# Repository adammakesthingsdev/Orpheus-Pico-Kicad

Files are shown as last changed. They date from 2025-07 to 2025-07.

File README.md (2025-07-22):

# Orpheus Pico
## About this repo
Welcome to the Kicad port of the Orpheus Pico, Hack Club's very own Raspberry Pi Pico compatible microcontroller!
This repository contains both the project files and built gerbers for ordering through JLCPCB.
Please note, **ordering is at your own risk**: I will not be held accountable if you have problems due to mistakes made ordering or issues with the project.

## Ordering
For information on ordering these boards, please refer to ORDERING.md.

## Licensing / other info
An official license for this project is TBD.
For now, you can:
- Use this project for inspiration and derivatives
- Order Orpheus Picos for **non-commercial** purposes: This means you cannot sell them, even at cost

Please get in touch with me (@adammakesthings on Hack Club Slack or adam@hackclub.com) if you are planning on selling Orpheus Picos or ordering large quantities.  

My final ask is that if you order any Orpheus Picos for any reason, I ask that you please keep my name and attribution on them. Again, please get in touch if this doesn't work for you.  
  
-Adam G

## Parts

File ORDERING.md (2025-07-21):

# Ordering info
These options are what I have used to order with JLCPCB. Feel free to tweak if you want, but this is what I recommend!
If an option isn't specified, assume it's the default.

- 2 layers
- Delivery format: Panel by JLCPCB.
  - Optional - this is just a whole lot cheaper!
  - Choose whatever panel size you want - I've had good luck with 2x5 boards and 5mm edges.
- 1.6mm thickness
- Black board color, or something else if you're feeling it!
- If you care about the art and aesthetics, go with ENIG. If you want em as cheap as possible, go with either of the HASLs.
- Mark on PCB: Remove mark. This removes the JLCPCB auto order number that's otherwise arbitrarily placed on your silkscreen
- PCB assembly: Top layer.
  - Unless you're changing something here, just click through the prompts.

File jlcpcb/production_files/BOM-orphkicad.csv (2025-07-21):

Comment | Designator | Footprint | LCSC | Quantity
1K | R10,R2,R7 | R_0402_1005Metric | C11702 | 3
100nF | C1,C13,C14,C2,C3,C4,C5,C6,C8 | C_0402_1005Metric | C1525 | 9
10uF | C15,C16 | C_0402_1005Metric | C15525 | 2
22pF | C10,C9 | C_0402_1005Metric | C1555 | 2
10uF | C12 | C_0805_2012Metric | C15850 | 1
1N5819WS | D1 | D_SOD-323 | C191023 | 1
RP2040 | U1 | QFN-56-1EP_7x7mm_P0.4mm_EP3.2x3.2mm | C2040 | 1
LED_PWR | D2 | LED_0603_1608Metric | C2286 | 1
27R | R3,R4 | R_0402_1005Metric | C25100 | 2
330R | R9 | R_0402_1005Metric | C25104 | 1
470R | R8 | R_0402_1005Metric | C25117 | 1
10K | R1 | R_0402_1005Metric | C25744 | 1
5K1 | R5,R6 | R_0402_1005Metric | C25905 | 2
USB_C_Receptacle_USB2.0_16P | J1 | USB-C-SMD_TYPE-C-6PIN-2MD-073 | C2765186 | 1
W25Q16JVUXIQ | U2 | Winbond_USON-8-1EP_3x2mm_P0.5mm_EP0.2x1.6mm | C2843335 | 1
BTN_BOOT | SW1,SW2,SW3 | SW-SMD_L3.9-W3.0-P4.45 | C455280 | 3
USBLC6-2SC6 | U3 | SOT-23-6 | C5180249 | 1
1uF | C11,C7 | C_0402_1005Metric | C52923 | 2
LED_RGB | D4 | LED-SMD_4P-L1.6-W1.5_XL-1615RGBC-WS2812B | C5349954 | 1
ME2135A33M6G | U4 | SOT-23-6 | C610271 | 1
X322512MSB4SI | X1 | Crystal_SMD_3225-4Pin_3.2x2.5mm | C9002 | 1
LED_USR | D3 | LED_0603_1608Metric | C965804 | 1

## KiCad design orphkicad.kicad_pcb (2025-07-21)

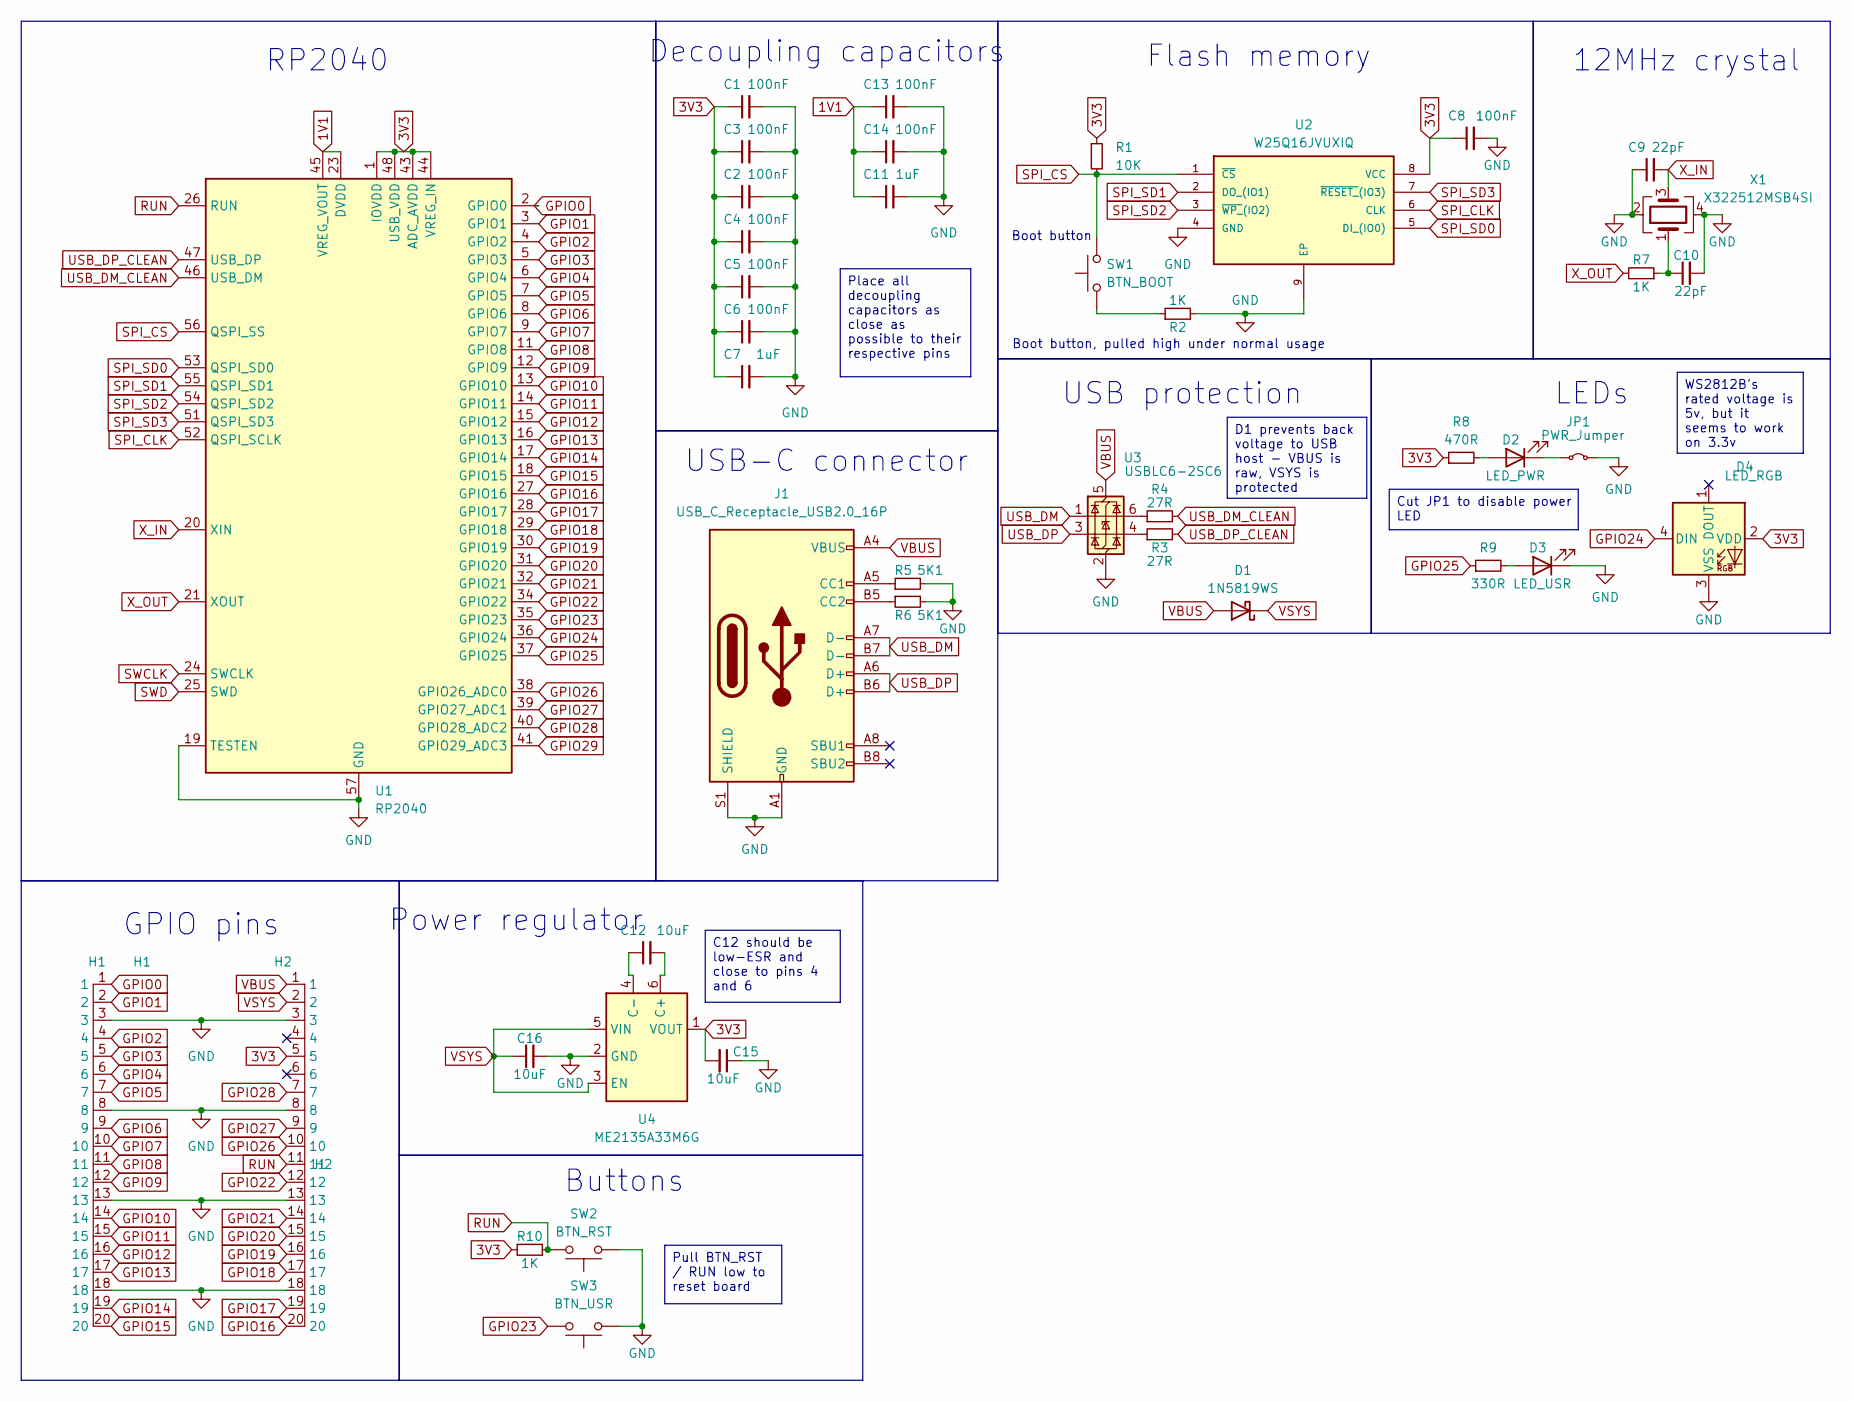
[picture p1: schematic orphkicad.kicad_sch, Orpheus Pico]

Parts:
C1, C2, C3, C4, C5, C6, C8, C13, C14: 100nF; C_0402_1005Metric
C7, C11: 1uF; C_0402_1005Metric
C9, C10: 22pF; C_0402_1005Metric
C12: 10uF; C_0805_2012Metric
C15, C16: 10uF; C_0402_1005Metric
D1: 1N5819WS; D_SOD-323
D2: LED_PWR; LED_0603_1608Metric
D3: LED_USR; LED_0603_1608Metric
D4: LED_RGB; LED-SMD_4P-L1.6-W1.5_XL-1615RGBC-WS2812B
H1: H1; OrphPicoHeaders
H2: H2; OrphPicoHeaders
J1: USB_C_Receptacle_USB2.0_16P; USB-C-SMD_TYPE-C-6PIN-2MD-073
JP1: PWR_Jumper; SolderJumper-2_P1.3mm_Bridged2Bar_RoundedPad1.0x1.5mm
R1: 10K; R_0402_1005Metric
R2, R7, R10: 1K; R_0402_1005Metric
R3, R4: 27R; R_0402_1005Metric
R5, R6: 5K1; R_0402_1005Metric
R8: 470R; R_0402_1005Metric
R9: 330R; R_0402_1005Metric
SW1: BTN_BOOT; SW-SMD_L3.9-W3.0-P4.45
SW2: BTN_RST; SW-SMD_L3.9-W3.0-P4.45
SW3: BTN_USR; SW-SMD_L3.9-W3.0-P4.45
U1: RP2040; QFN-56-1EP_7x7mm_P0.4mm_EP3.2x3.2mm
U2: W25Q16JVUXIQ; Winbond_USON-8-1EP_3x2mm_P0.5mm_EP0.2x1.6mm; MANUFACTURER_PART_NUMBER W25Q16JVUXIQ; LCSC C2843335
U3: USBLC6-2SC6; SOT-23-6
U4: ME2135A33M6G; SOT-23-6; LCSC C610271
X1: X322512MSB4SI; Crystal_SMD_3225-4Pin_3.2x2.5mm; LCSC C9002

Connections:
1V1: C11.1, C13.1, C14.1, U1.23 (DVDD), U1.45 (VREG_VOUT), U1.50 (DVDD)
3V3: C1.1, C2.1, C3.1, C4.1, C5.1, C6.1, C7.1, C8.1, C15.2, D4.2 (VDD), H2.5, R1.1, R8.1, R10.2, U1.1 (IOVDD), U1.10 (IOVDD), U1.22 (IOVDD), U1.33 (IOVDD), U1.42 (IOVDD), U1.43 (ADC_AVDD), U1.44 (VREG_IN), U1.48 (USB_VDD), U1.49 (IOVDD), U2.8 (VCC), U4.1 (VOUT)
GND: C1.2, C2.2, C3.2, C4.2, C5.2, C6.2, C7.2, C8.2, C9.1, C10.2, C11.2, C13.2, C14.2, C15.1, C16.2, D3.1 (K), D4.3 (VSS), H1.3, H1.8, H1.13, H1.18, H2.3, H2.8, H2.13, H2.18, J1.A1 (GND), J1.B1 (GND), J1.S1 (SHIELD), JP1.2 (B), R2.2, R5.2, R6.2, SW2.1, SW3.1, U1.19 (TESTEN), U1.57 (GND), U2.4 (GND), U2.9 (EP), U3.2 (GND), U4.2 (GND), X1.2, X1.4
GPIO0: H1.1, U1.2 (GPIO0)
GPIO1: H1.2, U1.3 (GPIO1)
GPIO2: H1.4, U1.4 (GPIO2)
GPIO3: H1.5, U1.5 (GPIO3)
GPIO4: H1.6, U1.6 (GPIO4)
GPIO5: H1.7, U1.7 (GPIO5)
GPIO6: H1.9, U1.8 (GPIO6)
GPIO7: H1.10, U1.9 (GPIO7)
GPIO8: H1.11, U1.11 (GPIO8)
GPIO9: H1.12, U1.12 (GPIO9)
GPIO10: H1.14, U1.13 (GPIO10)
GPIO11: H1.15, U1.14 (GPIO11)
GPIO12: H1.16, U1.15 (GPIO12)
GPIO13: H1.17, U1.16 (GPIO13)
GPIO14: H1.19, U1.17 (GPIO14)
GPIO15: H1.20, U1.18 (GPIO15)
GPIO16: H2.20, U1.27 (GPIO16)
GPIO17: H2.19, U1.28 (GPIO17)
GPIO18: H2.17, U1.29 (GPIO18)
GPIO19: H2.16, U1.30 (GPIO19)
GPIO20: H2.15, U1.31 (GPIO20)
GPIO21: H2.14, U1.32 (GPIO21)
GPIO22: H2.12, U1.34 (GPIO22)
GPIO23: SW3.2, U1.35 (GPIO23)
GPIO24: D4.4 (DIN), U1.36 (GPIO24)
GPIO25: R9.1, U1.37 (GPIO25)
GPIO26: H2.10, U1.38 (GPIO26_ADC0)
GPIO27: H2.9, U1.39 (GPIO27_ADC1)
GPIO28: H2.7, U1.40 (GPIO28_ADC2)
GPIO29: U1.41 (GPIO29_ADC3)
unnamed: C10.1, R7.1, X1.1
unnamed: D2.2 (A), R8.2
unnamed: D2.1 (K), JP1.1 (A)
unnamed: D3.2 (A), R9.2
unnamed: J1.A5 (CC1), R5.1
unnamed: J1.B5 (CC2), R6.1
unnamed: R2.1, SW1.1
unnamed: R3.1, U3.4 (I/O2)
unnamed: R4.1, U3.6 (I/O1)
unnamed: C12.2, U4.6 (C+)
unnamed: C12.1, U4.4 (C-)
RUN: H2.11, R10.1, SW2.2, U1.26 (RUN)
SPI_CLK: U1.52 (QSPI_SCLK), U2.6 (CLK)
SPI_CS: R1.2, SW1.2, U1.56 (QSPI_SS), U2.1 (~CS)
SPI_SD0: U1.53 (QSPI_SD0), U2.5 (DI_(IO0))
SPI_SD1: U1.55 (QSPI_SD1), U2.2 (DO_(IO1))
SPI_SD2: U1.54 (QSPI_SD2), U2.3 (~WP_(IO2))
SPI_SD3: U1.51 (QSPI_SD3), U2.7 (~RESET_(IO3))
SWCLK: U1.24 (SWCLK)
SWD: U1.25 (SWD)
USB_DM: J1.A7 (D-), J1.B7 (D-), U3.1 (I/O1)
USB_DM_CLEAN: R4.2, U1.46 (USB_DM)
USB_DP: J1.A6 (D+), J1.B6 (D+), U3.3 (I/O2)
USB_DP_CLEAN: R3.2, U1.47 (USB_DP)
VBUS: D1.2 (A), H2.1, J1.A4 (VBUS), J1.B4 (VBUS), U3.5 (VBUS)
VSYS: C16.1, D1.1 (K), H2.2, U4.3 (EN), U4.5 (VIN)
X_IN: C9.2, U1.20 (XIN), X1.3
X_OUT: R7.2, U1.21 (XOUT)

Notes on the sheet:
Power regulator
Flash memory
Boot button, pulled high under normal usage
USB-C connector
Decoupling capacitors
USB protection
LEDs
Boot button
RP2040
GPIO pins
Buttons
12MHz crystal
Pull BTN_RST / RUN low to reset board
Place all decoupling capacitors as close as possible to their respective pins
WS2812B's rated voltage is 5v, but it seems to work on 3.3v
C12 should be low-ESR and close to pins 4 and 6
Cut JP1 to disable power LED
D1 prevents back voltage to USB host - VBUS is raw, VSYS is protected

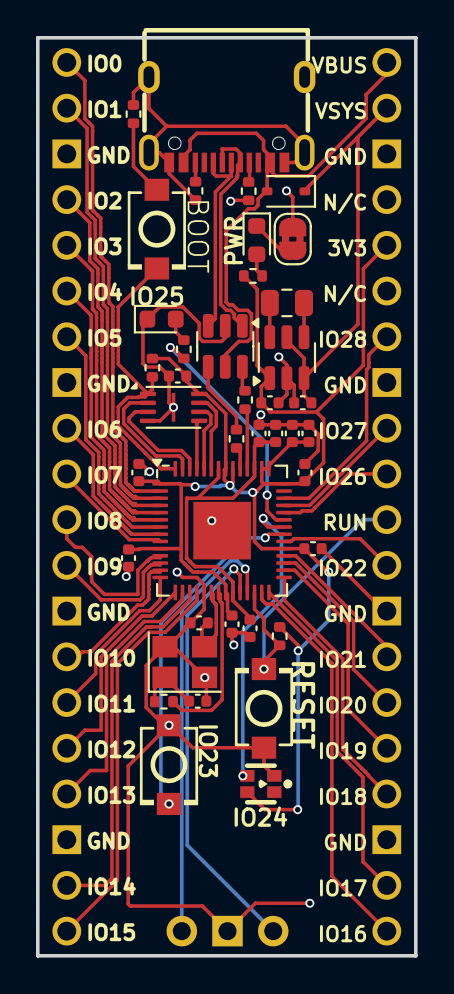
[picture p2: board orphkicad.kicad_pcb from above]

Board: 2 copper layers, 21.0 x 51.0 mm, 42 parts (0 on the bottom side), 58 nets.

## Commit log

2025-07-21 Initial commit - adds JLCPCB production files and KiCad project files
    [BOM-orphkicad.csv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]
2025-07-21 Dejankifies back plane routing
    Routing on the back plane is now a little less janky, at the cost of a more segmented back plane.
    [orphkicad-CuBottom.gbr, orphkicad-CuTop.gbr, orphkicad-EdgeCuts.gbr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]
